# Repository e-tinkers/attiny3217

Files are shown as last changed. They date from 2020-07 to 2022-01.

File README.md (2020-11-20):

## E-Tinkers ATtiny3217 Arduino-Compatible Development Board

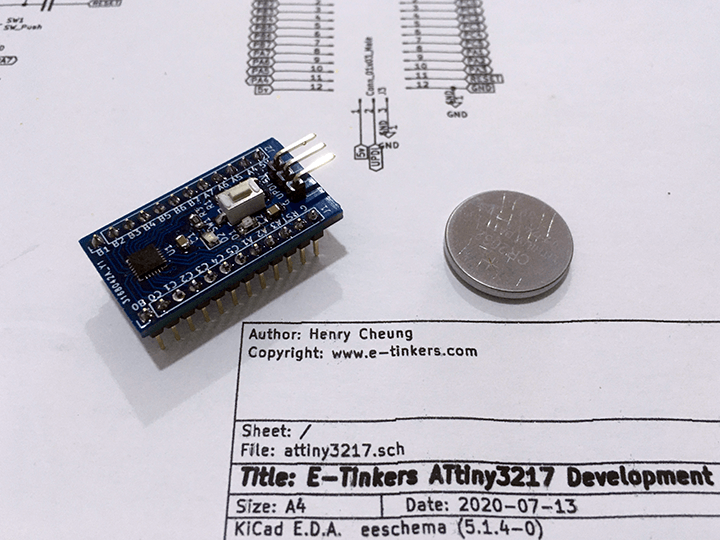
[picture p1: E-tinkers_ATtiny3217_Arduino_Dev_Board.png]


This is the hardware design repository for a tiny (34.6mm * 19.3mm) Arduino-compatible Development Board based on ATtiny3271.

ATtiny3217 is a modern AVR microcontroller chip from Microchip that could potentially replace ATmega328p that is widely used in official Arduino boards. Traditionally the classic ATtiny family has low flash and SRAM memory size as well as low pin count, this has changed since the release of tinyAVR 0-series and 1-series MCUs in 2018. The following table shows ATtiny3217 offers almost all the features of an ATmega328p and more...

### Differences between ATmega328p and ATtiny3217
<table>
    <tr>
        <th></th>
        <th>ATmega328p</th>
        <th>ATtiny3217</th>
    </tr>
    <tr>
        <td>Flash Memory</td>
        <td>32K Bytes</td>
        <td>32K Bytes</td>
    </tr>
    <tr>
        <td>SRAM</td>
        <td>2K Bytes</td>
        <td>2K Bytes</td>
    </tr>
    <tr>
        <td>EEPROM</td>
        <td>1K Bytes</td>
        <td>256 Bytes</td>
    </tr>
    <tr>
        <td>UART</td>
        <td>1</td>
        <td>1</td>
    </tr>
    <tr>
        <td>SPI</td>
        <td>1</td>
        <td>1</td>
    </tr>
    <tr>
        <td>I2C</td>
        <td>1</td>
        <td>1</td>
    </tr>
    <tr>
        <td>ADC Channel</td>
        <td>8 x 10-bit</td>
        <td>12 x 10-bit</td>
    </tr>
    <tr>
        <td>PWM Channel</td>
        <td>6</td>
        <td>8</td>
    </tr>
    <tr>
        <td>IO</td>
        <td>23</td>
        <td>22</td>
    </tr>
    <tr>
        <td rowspan="3">Timer</td>
        <td rowspan="3">
        2 x 8-bit<br>
        1 x 16-bit
        </td>
        <td rowspan="3">
        1 x 16-bit(TCA)<br>
        2 x 16-bit (TCB)<br>
        1 x 12-bit (TCD)
        </td>
    </tr>
</table>

There are several notible features that are not available in ATmega328p, such as:
<ul>
<li>Three 8-bit DACs with one external channel</li>
<li>Configurable Custom Logic/Lookup Table</li>
<li>16-bit Real-time Counter</li>
<li>6 Event System Channels</li>
<li>Periperral Touch Controller</li>
<li>5 Configurable Internal Voltage References (versus ATmega328p's 1 at VCC level)</li>
</ul>

Read my [blog](https://www.e-tinkers.com/2020/07/arduino-compatible-development-board-with-attiny3217) for more details on how to use it as an Arduino.

## E-Tinkers ATtiny3217 Development Board Pinout
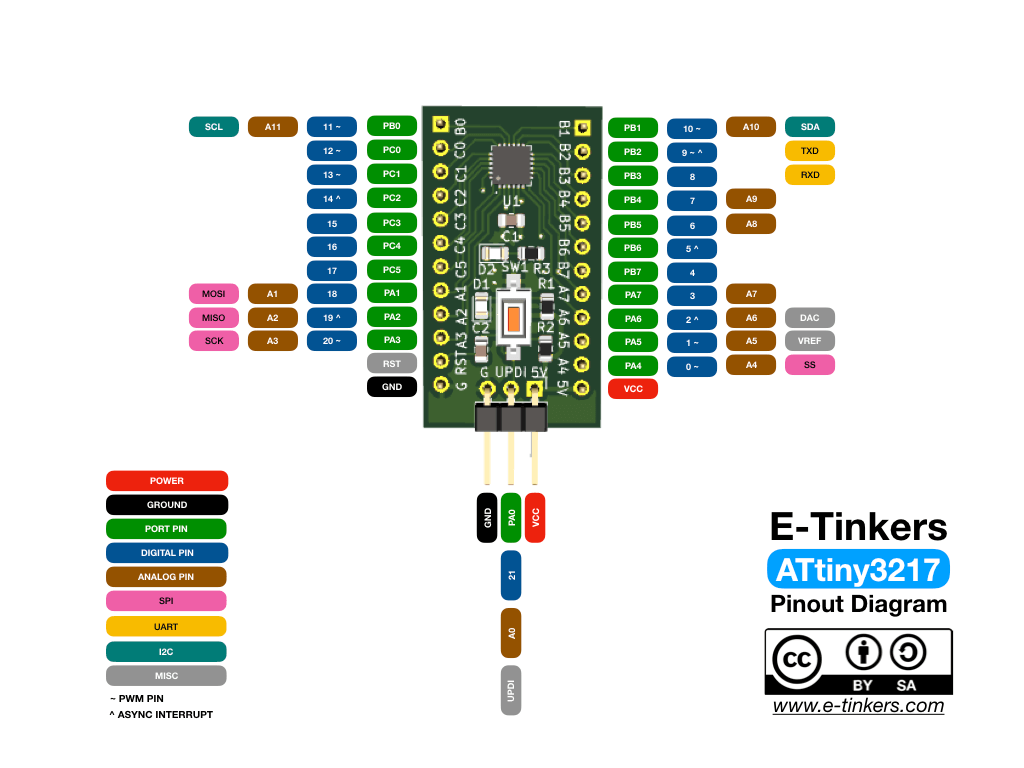
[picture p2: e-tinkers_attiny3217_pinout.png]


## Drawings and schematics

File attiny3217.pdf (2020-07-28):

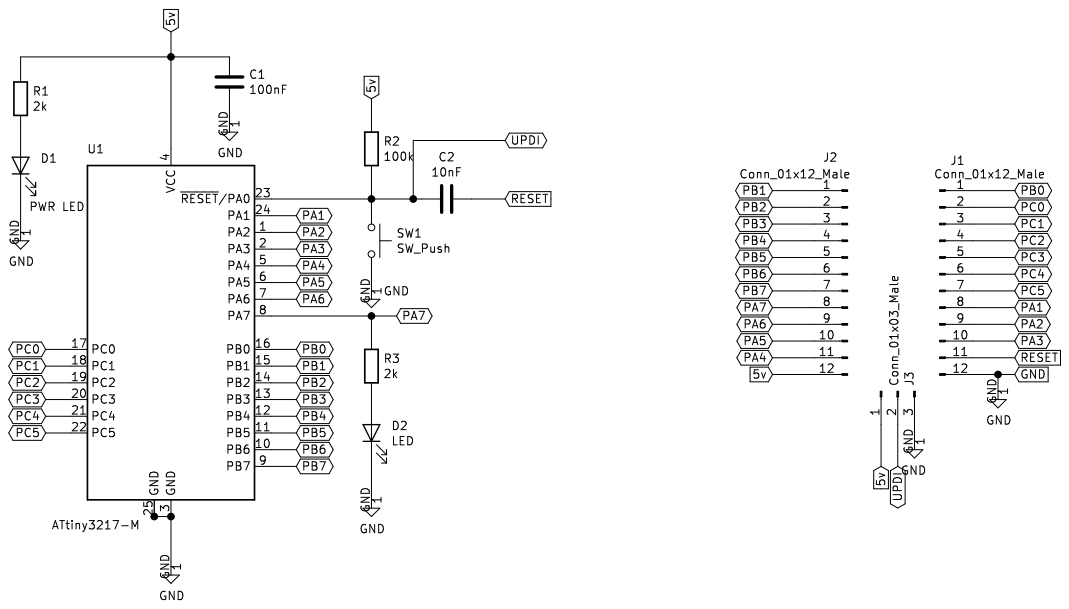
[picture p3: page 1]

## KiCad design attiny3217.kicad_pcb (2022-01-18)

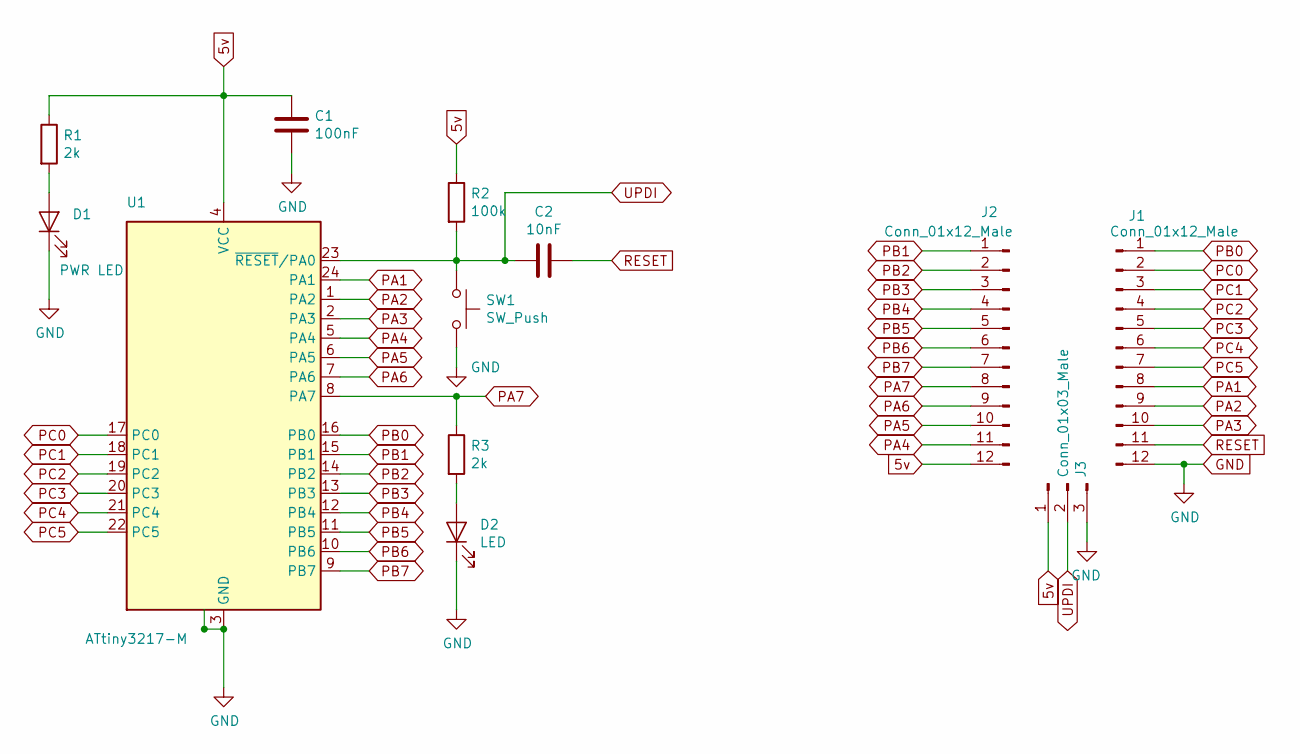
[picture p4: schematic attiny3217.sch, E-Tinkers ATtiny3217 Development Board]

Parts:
C1: 100nF; C_0805_2012Metric
C2: 10nF; C_0805_2012Metric
D1: PWR LED; LED_0805_2012Metric
D2: LED; LED_0805_2012Metric
J1, J2: Conn_01x12_Male; PinHeader_1x12_P2.54mm_Vertical
J3: Conn_01x03_Male; PinHeader_1x03_P2.54mm_Horizontal
R1, R3: 2k; R_0805_2012Metric
R2: 100k; R_0805_2012Metric
SW1: SW_Push; SW_SPST_CK_RS282G05A3
U1: ATtiny3217-M; QFN-24-1EP_4x4mm_P0.5mm_EP2.6x2.6mm

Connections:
5v: C1.1, J2.12, J3.1, R1.1, R2.1, U1.4 (VCC)
GND: C1.2, D1.1 (K), D2.1 (K), J1.12, J3.3, SW1.2, U1.3 (GND), U1.25 (GND)
unnamed: D1.2 (A), R1.2
unnamed: D2.2 (A), R3.2
PA1: J1.8, U1.24 (PA1)
PA2: J1.9, U1.1 (PA2)
PA3: J1.10, U1.2 (PA3)
PA4: J2.11, U1.5 (PA4)
PA5: J2.10, U1.6 (PA5)
PA6: J2.9, U1.7 (PA6)
PA7: J2.8, R3.1, U1.8 (PA7)
PB0: J1.1, U1.16 (PB0)
PB1: J2.1, U1.15 (PB1)
PB2: J2.2, U1.14 (PB2)
PB3: J2.3, U1.13 (PB3)
PB4: J2.4, U1.12 (PB4)
PB5: J2.5, U1.11 (PB5)
PB6: J2.6, U1.10 (PB6)
PB7: J2.7, U1.9 (PB7)
PC0: J1.2, U1.17 (PC0)
PC1: J1.3, U1.18 (PC1)
PC2: J1.4, U1.19 (PC2)
PC3: J1.5, U1.20 (PC3)
PC4: J1.6, U1.21 (PC4)
PC5: J1.7, U1.22 (PC5)
RESET: C2.1, J1.11
UPDI: C2.2, J3.2, R2.2, SW1.1, U1.23 (~RESET~/PA0)

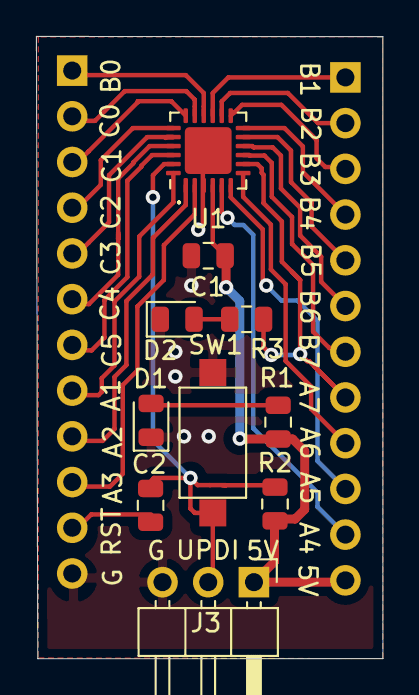
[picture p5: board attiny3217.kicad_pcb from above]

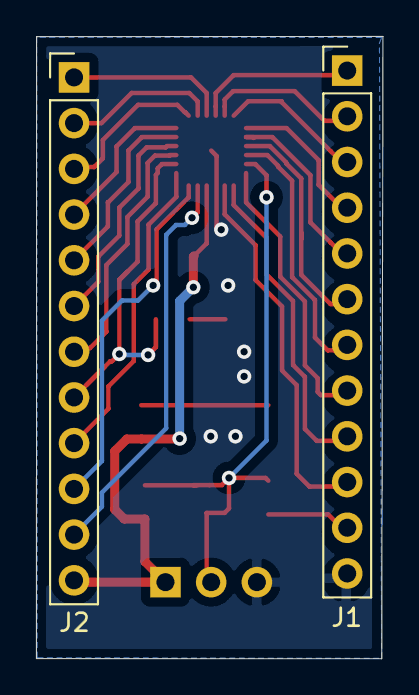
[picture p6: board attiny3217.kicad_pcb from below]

Board: 2 copper layers, 19.3 x 34.6 mm, 12 parts (2 on the bottom side), 27 nets.
